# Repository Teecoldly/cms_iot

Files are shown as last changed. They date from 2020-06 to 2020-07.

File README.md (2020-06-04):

@teecoldly   <br>
Libaryname version <br>
DHT 1.3.6   https://github.com/adafruit/DHT-sensor-library <br>
sps30 1.3.7 https://github.com/paulvha/sps30 <br>
Air_Quality_Sensor 1.0.1 https://github.com/Seeed-Studio/Grove_Air_quality_Sensor <br>
MAX44009 1.0.0 https://github.com/dantudose/MAX44009 <br>
SocketIoClient 0.3 https://github.com/timum-viw/socket.io-client

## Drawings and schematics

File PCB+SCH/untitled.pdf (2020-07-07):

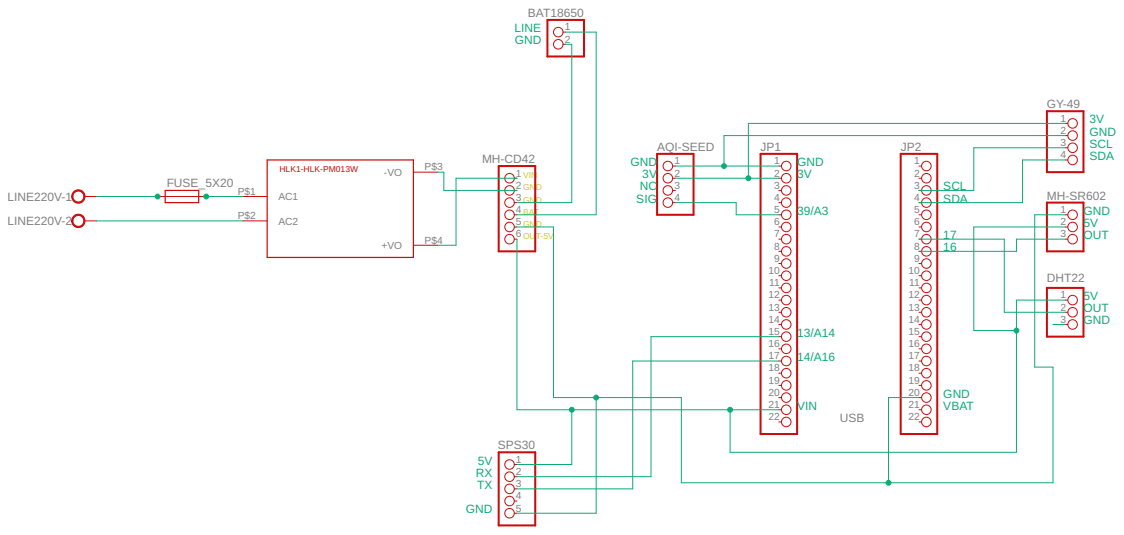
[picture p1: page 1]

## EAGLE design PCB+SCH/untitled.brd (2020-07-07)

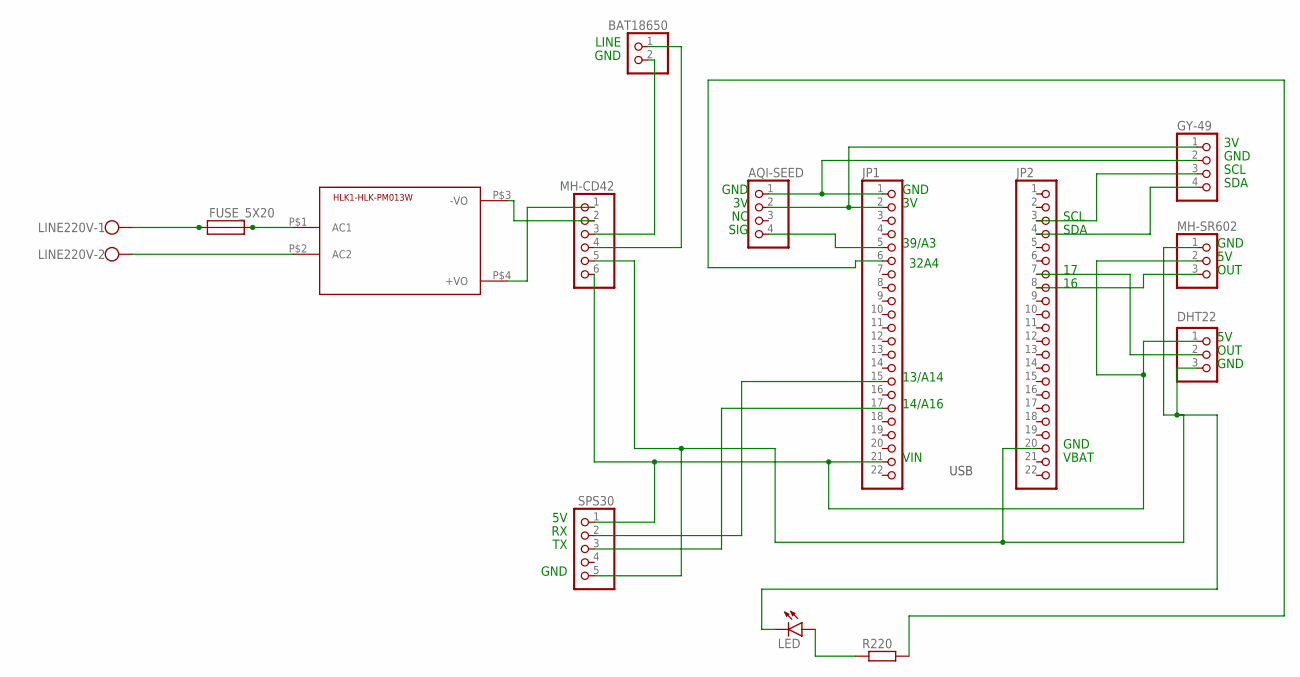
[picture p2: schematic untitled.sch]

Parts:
AQI-SEED: PINHD-1X4; 1X04
BAT18650: PINHD-1X2; 1X02
FUSE_5X20: FH_5X20
GY-49: PINHD-1X4; 1X04
HLK1-HLK-PM013W: HLK-PM013W; HLK-PM01
JP1, JP2: PINHD-1X22; 1X22
JP6: DHT22; 1X03
LED: LED3MM
LINE220V: W237-102
MH-CD42: PINHD-1X6; 1X06
MH-SR602: PINHD-1X3; 1X03
R220: R-EU_0204/5; 0204/5
SPS30: PINHD-1X5; 1X05

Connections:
unnamed: FUSE_5X20.1A, FUSE_5X20.1B, LINE220V.1
unnamed: FUSE_5X20.2A, FUSE_5X20.2B, HLK1-HLK-PM013W.P$1 (AC1)
unnamed: HLK1-HLK-PM013W.P$2 (AC2), LINE220V.2
unnamed: HLK1-HLK-PM013W.P$4 (+VO), MH-CD42.1
unnamed: HLK1-HLK-PM013W.P$3 (-VO), MH-CD42.2
unnamed: JP1.21, JP6.1, MH-CD42.6, MH-SR602.2, SPS30.1
unnamed: JP2.20, JP6.3, LED.K (C), MH-CD42.5, MH-SR602.1, SPS30.5
unnamed: JP2.7, JP6.2
unnamed: JP2.8, MH-SR602.3
unnamed: GY-49.4, JP2.4
unnamed: GY-49.3, JP2.3
unnamed: AQI-SEED.2, GY-49.1, JP1.2
unnamed: AQI-SEED.1, GY-49.2, JP1.1
unnamed: AQI-SEED.4, JP1.5
unnamed: JP1.15, SPS30.2
unnamed: LED.A, R220.1
unnamed: JP1.17, SPS30.3
unnamed: BAT18650.2, MH-CD42.3
unnamed: BAT18650.1, MH-CD42.4
unnamed: JP1.6, R220.2

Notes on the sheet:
GND
39/A3
VIN
USB
OUT
SCL
SDA
SIG
VBAT
14/A16
13/A14
LINE
32A4

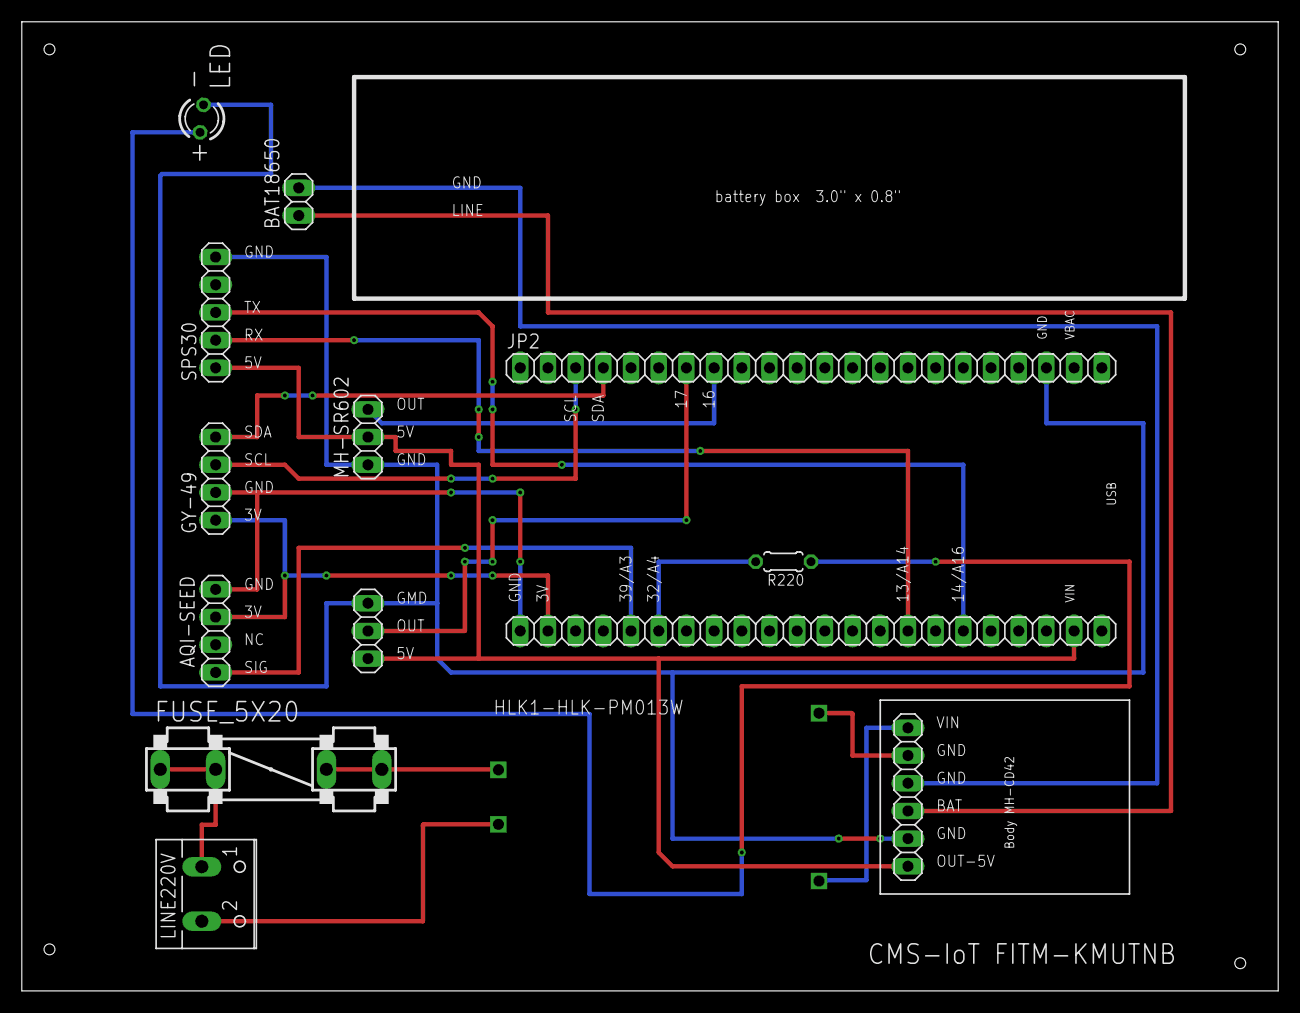
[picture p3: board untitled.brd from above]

Board: 2 copper layers, 115.2 x 88.9 mm, 14 parts (0 on the bottom side), 20 nets.

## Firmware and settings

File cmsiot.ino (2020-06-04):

//Include Zone
#include "DHT.h"
#include "sps30.h"
#include "Air_Quality_Sensor.h"
#include <Wire.h>
#include <MAX44009.h>
#include <WiFi.h>
#include <HTTPClient.h>
#include <SocketIoClient.h>

#define cms_iot_key "key on web site"//34.87.72.130

/* SPS30 CONNECTION
  RED 5V
  Purple GND
  Blue no connect
  Green pin 17 RX2
  Yellow pin 16 TX2

  DHT
  VCC 5V
  DATA PIN 2

  CCS881
  VCC 3.3 V
  SCl -----SCL1
  SDA -----SDA1

*/
char host[] = "34.87.72.130"; // Ip Address
int port = 3001; // Socket.IO Port Address
/////////////////////////////////////
////// ESP32 Socket.IO Client //////
///////////////////////////////////

SocketIoClient webSocket;
WiFiClient client;


// DEFINE ZONE
#define SP30_COMMS SERIALPORT1
#define TX_PIN 13 //D1
#define RX_PIN 14 //D2
#define DEBUG 0
#define pir 16 //  pin pir
#define DHTPIN 17     // Digital pin connected to the DHT sensor
#define DHTTYPE DHT22   // DHT 22  (AM2302), AM2321
#define led 32
DHT dht(DHTPIN, DHTTYPE);

//PIN DEFINE ZONE
//int pir = 16; //D7
MAX44009 light;
//AirQuality 
AirQualitySensor sensor(A3);
int current_quality =-1; 

void Errorloop(char *mess, uint8_t r);
void ErrtoMess(char *mess, uint8_t r);
int tempp;
float humi;
// wifi setting
const char* ssid = "wifiname 2.4g";   
const char* password =  "password";


SPS30 sps30;

void setup()
{
  Serial.begin(115200);
  
  pinMode(led, OUTPUT);
  digitalWrite(led, HIGH);
  delay(4000);   //Delay needed before calling the WiFi.begin

  WiFi.begin(ssid, password);

  while (WiFi.status() != WL_CONNECTED) { //Check for the connection
    delay(1000);
    Serial.println("Connecting to WiFi..");
  }
  Serial.println("Connected to the WiFi network");
  
    delay(5000);
   if (sensor.init()) {
        Serial.println("Sensor AQI ready.");
    } else {
        Serial.println("Sensor AQI ERROR!");
    }

 
  //pinMode(pir, INPUT);


  // set driver debug level
  sps30.EnableDebugging(DEBUG);

  // set pins to use for softserial and Serial1 on ESP32
  if (TX_PIN != 0 && RX_PIN != 0) sps30.SetSerialPin(RX_PIN, TX_PIN);

  // Begin communication channel;
  if (sps30.begin(SP30_COMMS) == false) {
    Errorloop("could not initialize communication channel.", 0);
  }

  // check for SPS30 connection
  if (sps30.probe() == false) {
    Errorloop("could not probe / connect with SPS30.", 0);
  }
  else
    Serial.println(F("Detected SPS30."));

  // reset SPS30 connection
  if (sps30.reset() == false) {
    Errorloop("could not reset.", 0);
  }
   

    delay(5000);
 
   
  
  dht.begin();
  Wire.begin();
  
  delay(500);
  
  light.begin();
  
   pinMode(pir, INPUT);
   
  webSocket.begin(host, port);
    digitalWrite(led, LOW);
}
void checkLEDState() {
 
  // Reading temperature or humidity takes about 250 milliseconds!
  // Sensor readings may also be up to 2 seconds 'old' (its a very slow sensor)
  float h = dht.readHumidity();
  // Read temperature as Celsius (the default)
  float t = dht.readTemperature();
  // Read temperature as Fahrenheit (isFahrenheit = true)
  float f = dht.readTemperature(true);

  // Check if any reads failed and exit early (to try again).
  if (isnan(h) || isnan(t) || isnan(f)) {
    Serial.println(F("Failed to read from DHT sensor!"));
    return;
  }
  /*===============================================================*/

  //  long state = digitalRead(pir);
  int state_server_pir = 0 ;
  
    long state = digitalRead(pir);
    if (state == HIGH) {

      Serial.println("Motion detected!");
      state_server_pir = 1  ;
  
    }
    else {

      Serial.println("Motion absent!");
      state_server_pir = 0 ;
 
    }
 

  String str = "{\"key\":\"" + String(cms_iot_key) + "\",\"humid\":\"" + String(h) + "\",\"temp\":\"" + String(t) + "\",\"pm10\":\"" + String(dustbuster10()) + "\",\"pm25\":\"" + String(dustbuster25()) + "\",\"lux\":\"" + String(lighter()) + "\",\"carbon\":\"" + String(aqi()) + "\",\"pir\":\"" + String(state_server_pir) + "\"}";
  Serial.println(str);
    char msg[str.length() + 1] ;
    str.toCharArray(msg, str.length() + 1);
    Serial.println(msg);
    webSocket.emit("iot", msg);
}
void loop()
{
 
  webSocket.loop();
  checkLEDState();
 
}

float lighter() {
  
  float lux = light.get_lux();
  return (lux);
}



float dustbuster10() {

  uint8_t ret, error_cnt = 0;
  struct sps_values val;
  do {

    ret = sps30.GetValues(&val);
  } while (ret != ERR_OK);
  float duster = val.MassPM1;

  return (duster);


}
float dustbuster25() {

  uint8_t ret, error_cnt = 0;
  struct sps_values val;
  do {

    ret = sps30.GetValues(&val);
  } while (ret != ERR_OK);
  float duster = val.MassPM2;
  return (duster);


}
void Errorloop(char *mess, uint8_t r)
{
  if (r) ErrtoMess(mess, r);
  else Serial.println(mess);
  Serial.println(F("Program on hold"));
  for (;;) delay(100000);
}
void ErrtoMess(char *mess, uint8_t r)
{
  char buf[80];

  Serial.print(mess);

  sps30.GetErrDescription(r, buf, 80);
  Serial.println(buf);
}
int aqi(){

    int quality = sensor.slope();

    Serial.print("Sensor value: ");
    Serial.println(sensor.getValue());

    if (quality == AirQualitySensor::FORCE_SIGNAL) {
        Serial.println("High pollution! Force signal active.");
        return 4;
    } else if (quality == AirQualitySensor::HIGH_POLLUTION) {
        Serial.println("High pollution!");
        return 3;
    } else if (quality == AirQualitySensor::LOW_POLLUTION) {
        Serial.println("Low pollution!");
        return 2;
    } else if (quality == AirQualitySensor::FRESH_AIR) {
        Serial.println("Fresh air.");
        return 1;
    }
    return 99 ;
}
